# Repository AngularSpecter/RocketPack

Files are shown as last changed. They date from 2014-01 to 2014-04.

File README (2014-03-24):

*** Rocket Pack************************************

Project Synopsis
--------------------

Rocket pack is a development board based around the MSP430FR5739 microcontroller
and the Digi Xbee S3B Pro 900MHz zigbee radio.  The board is intended to 
facilitate broadcasting real time, high-rate sensor data over a range of several
hundred meters.  The board is designed to interface with custom built sensor 
packages, or with the TI sensorTag development board running custom firmware

Power Supply
----------------------
The board has on-board battery management designed specifically for single cell
lipo batteries, but will also take any voltage source between 3.3V and 5VDC.
The regualted 3.2V rail is availible on all three expansion headers as well as 
the CCdebugger header, which is designed specifically to power the sensorTag
development board.   

Communications
----------------------
The MSP430FR5739 contains two hardware USART's.  One USART is reserved for the
zigbee radio, while the other is broken out to both the serial data header and 
the ez430 programming/debug header.  All signals reqired for I2C, SPI or UART 
are availible on the serial data header

The firmware is written to buffer both inbound and outbound traffic.  The MCU 
pops bytes into the rx buffers in low power mode.  Once a line term char is RX'd,
LPM is exited and the full packet is processed.

No data is transmitted until a full packet is buffered.  Then it is transmitted
entirely before additional data is processed.  

Node power up sequence
-----------------------------------

sleep loop
-----------
1. Boot
2. Hold sensors in reset
3. Read and store radio address
4. Boot sensors
5. Read and store cal data
6. Sleep sensors

{
Auto discovery
---------------------
1. Poll magentometer
2. Broadcast host discover on trigger
3. Repeat until node select rxd
4. TX ACK
}

Wake up loop (on rx of node select)
-------------
7. TX ACK
8. Wait for command
   8a. Send cal data
   8b. Start data stream
  
On ~node select
----------------
1. Sleep sensors
2. Wait for wake up 

  Packet Formatting
  -----------------------------------------
  [0x01] [address] [0x00]
  host discover   0x01     Broadcast by the host to the base station to announce
                           its presence.
  [0x02] [command] [data] [0x00]                         
  command         0x02     Base -> node: command for remote node to execute
                           node -> base: return of command
                           
                  commands
                     0x01  Stop transmitting data
                     0x02  Start transmitting data
                     0x03  Change sensor profile
                     0x04  Reboot         

  cal data        0x03     Base -> node: Request calibration data 
                           node -> base: Return calibration data   
  
  data packet     0x04     node -> base: Data 

  node select     0x05     base -> node: address of node to be active..all other sleep

  ACK             0x06     command ACK
  
  NACK            0x07     command NACK
SensorTag
----------------------

 Errata
 ---------------------
 
 V0.1:
       Debug header location:  The location of the debug header interferes with 
       nearby pin headers, making it impossible to populate the debug header 
       with a right angle header and .1" pitch pin header.
       
       Specified load capacitors on the crystal are wrong.  The crystal will 
       stabilize on boot, but will not remain.
       
       Radio CONFIG pin is wired to MCU to allow easy entrance into command
       mode.  This should be connected to a different pin.

TO DO
------------------------

1.  MS430Firmware:  1.  Startup sleep mode -> poll mag and exit on high value
                    2.  Startup procedure -> broadcast calibration data
                    3.  Startup procedure -> read radio ID to store UID
                    4.  TX mirror         -> Prepend UID to TX'd packets
                    
2.  SensorTag       1.  Clean up firmware  -> remove deadwood
                    2.  
                    
3.  Labview         1.  Radio interface  ->  AT command mode control to select
                                             radio to listen to
                    2.  Sensor interface ->  Formalize calibration code
                    3.  Sensor interface ->  Formalize data processing
                    4.  Sensor interface ->  Add "remote globals"

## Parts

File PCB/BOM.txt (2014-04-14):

Index	Quantity	Part Number	Description	Customer Reference    Part ID

1   1 296-29235-1-ND     IC MCU 16BIT 16KB FRAM 38TSSOP       U3 
2   1 LTC1540CMS8#PBF-ND IC COMP NANOPOWER W/REF 8-MSOP       U2
3   1 296-17424-1-ND     IC REG LDO 3.2V 0.4A SOT23-5         U1

4 	2	311-1154-1-ND	CAP CER 22PF 50V 5% NPO 1206	            C7, C8
5	  1	311-1158-1-ND	CAP CER 47PF 50V 5% NPO 1206	            C6
6 	1 1276-1165-1-ND	CAP CER 0.1UF 50V 5% X7R 1206		        C4       
7 	1	1276-3085-1-ND	CAP CER 1UF  25V  5% X7R 1206		        C5
8 	1	311-1376-2-ND	CAP CER 10UF 16V Y5V 1206                 C3
9	  1	478-5784-1-ND	CAP CER 0.47UF 50V  5% X7R 1206	          C6
10	1	445-2344-1-ND	CAP CER 2200PF 630V 5% NP0 1206			      C1

11  1 311-47KERTR-ND      RES 47K OHM 1/4W 5% 1206 SMD        R1
12 	1	RMCF1206FT2M00CT-ND	RES 2M OHM 1/4W 1% 1206             R2
13	1	RHM1.18MCJCT-ND	    RES 1.18M OHM 1/4W 1% 1206 SMD      R3
14  1 311-100FRTR-ND      RES 100 OHM 1/4W 1% 1206 SMD        R4

15	1	XC1911CT-ND	CRYSTAL 32.768KHZ 12.5PF SMD                Q2
16  1 LTST-C150KGKT LED GREEN CLEAR 1206 SMD                  LED1

17	2	1212-1314-ND	SOCKET 4.2 MM SOLDER TAIL SINGLE
18  1 S9016E-06-ND	CONN HEADER .050" 6POS PCB R/A		
19	1	609-3754-ND	  CONN RECEPT 10POS DUAL VERT T/H

20	1	1175-1261-ND	CABLE CONNECT INTERNAL DVD .5M	

21	1	A9BBA-0603E-ND	FLEX CABLE - AFJ06A/AE06/AFJ06A

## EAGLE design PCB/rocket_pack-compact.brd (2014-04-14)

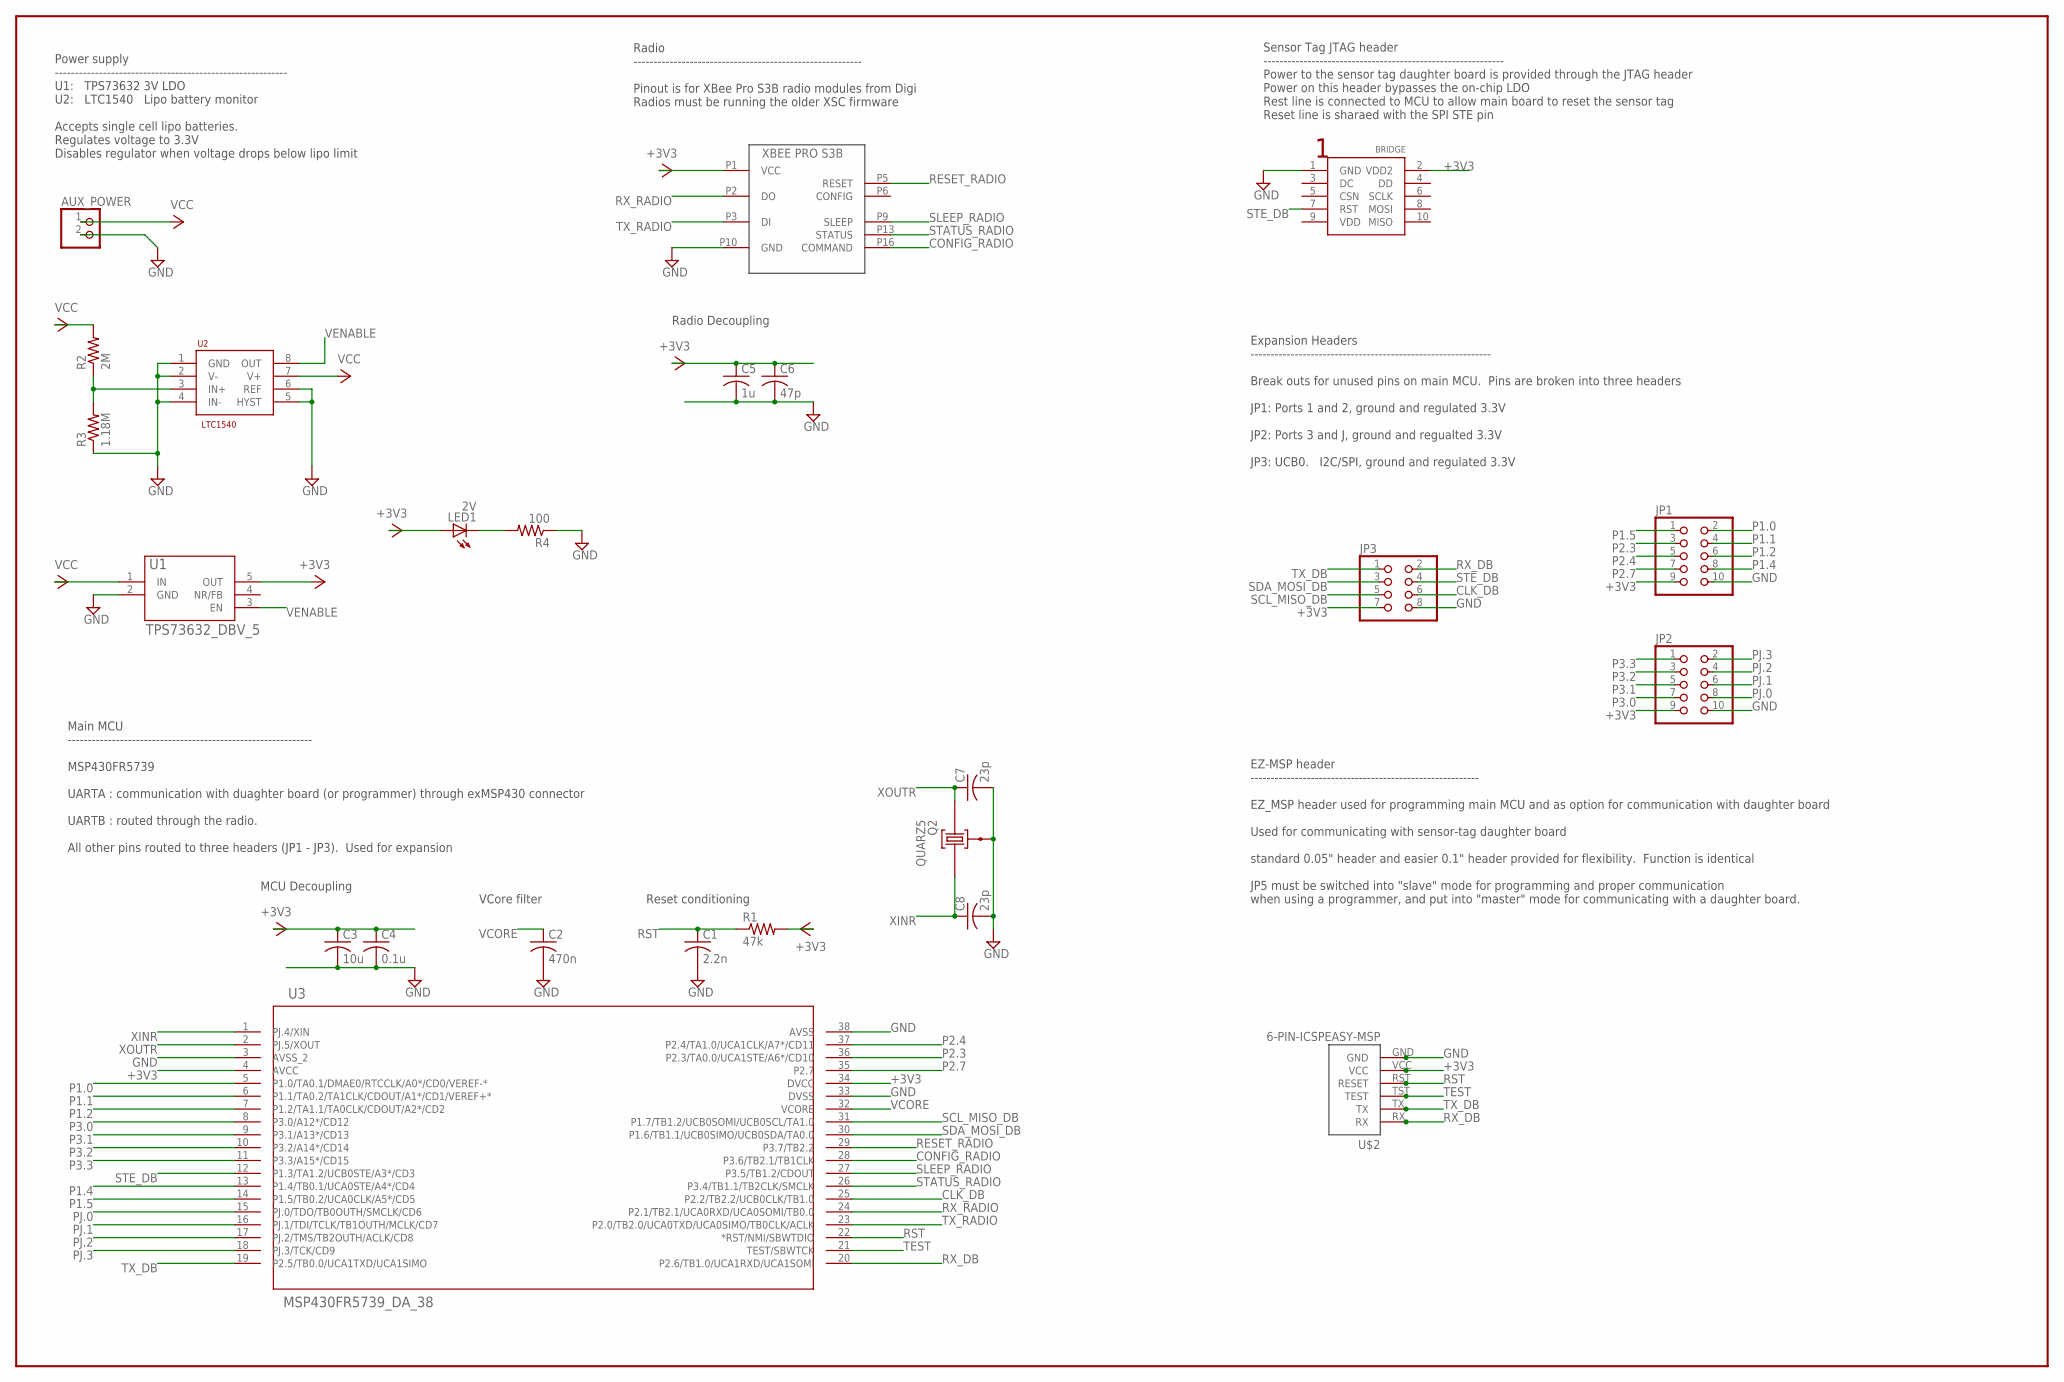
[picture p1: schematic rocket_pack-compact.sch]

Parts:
AUX_POWER: PINHD-1X2; 1X02
BRIDGE: CC-DEBUG; 2X5-1.27MM
C1: 2.2n; C1206
C2: 470n; C1206
C3: 10u; C1206
C4: 0.1u; C1206
C5: 1u; C1206
C6: 47p; C1206
C7, C8: 23p; C1206
JP1, JP2: PINHD-2X5; 2X05
JP3: PINHD-2X4; 2X04
LED1: 2V; 1206
Q2: QUARZ5
R1: 47k; R1206
R2: 2M; R1206
R3: 1.18M; R1206
R4: 100; R1206
U1: TPS73632_DBV_5; DBV5
U2: LTC1540; S8
U3: MSP430FR5739_DA_38; DA38
U$1: XBEE_PRO_S3B; PRO_S3B
U$2: 6-PIN-ICSPEASY-MSP; EASYMSP-6PIN

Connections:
+3V3: BRIDGE.2 (VDD2), C3.1, C4.1, C5.1, C6.1, JP1.9, JP2.9, JP3.7, LED1.A, R1.2, U1.5 (OUT), U3.4 (AVCC), U3.34 (DVCC), U$1.P1 (VCC), U$2.VCC
CLK_DB: JP3.6, U3.25 (P2.2/TB2.2/UCB0CLK/TB1.0)
CONFIG_RADIO: U3.28 (P3.6/TB2.1/TB1CLK), U$1.P16 (COMMAND)
GND: AUX_POWER.2, BRIDGE.1 (GND), C1.2, C2.2, C3.2, C4.2, C5.2, C6.2, C7.2, C8.2, JP1.10, JP2.10, JP3.8, Q2.GND@0 (0), R3.1, R4.1, U1.2 (GND), U2.1 (GND), U2.2 (V-), U2.4 (IN-), U2.5 (HYST), U2.6 (REF), U3.3 (AVSS_2), U3.33 (DVSS), U3.38 (AVSS), U$1.P10 (GND), U$2.GND
LED: LED1.C, R4.2
unnamed: R2.1, R3.2, U2.3 (IN+)
P1.0: JP1.2, U3.5 (P1.0/TA0.1/DMAE0/RTCCLK/A0*/CD0/VEREF-*)
P1.1: JP1.4, U3.6 (P1.1/TA0.2/TA1CLK/CDOUT/A1*/CD1/VEREF+*)
P1.2: JP1.6, U3.7 (P1.2/TA1.1/TA0CLK/CDOUT/A2*/CD2)
P1.4: JP1.8, U3.13 (P1.4/TB0.1/UCA0STE/A4*/CD4)
P1.5: JP1.1, U3.14 (P1.5/TB0.2/UCA0CLK/A5*/CD5)
P2.3: JP1.3, U3.36 (P2.3/TA0.0/UCA1STE/A6*/CD10)
P2.4: JP1.5, U3.37 (P2.4/TA1.0/UCA1CLK/A7*/CD11)
P2.7: JP1.7, U3.35 (P2.7)
P3.0: JP2.7, U3.8 (P3.0/A12*/CD12)
P3.1: JP2.5, U3.9 (P3.1/A13*/CD13)
P3.2: JP2.3, U3.10 (P3.2/A14*/CD14)
P3.3: JP2.1, U3.11 (P3.3/A15*/CD15)
PJ.0: JP2.8, U3.15 (PJ.0/TDO/TB0OUTH/SMCLK/CD6)
PJ.1: JP2.6, U3.16 (PJ.1/TDI/TCLK/TB1OUTH/MCLK/CD7)
PJ.2: JP2.4, U3.17 (PJ.2/TMS/TB2OUTH/ACLK/CD8)
PJ.3: JP2.2, U3.18 (PJ.3/TCK/CD9)
RESET_RADIO: U3.29 (P3.7/TB2.2), U$1.P5 (RESET)
RST: C1.1, R1.1, U3.22 (*RST/NMI/SBWTDIO), U$2.RST (RESET)
RX_DB: JP3.2, U3.20 (P2.6/TB1.0/UCA1RXD/UCA1SOMI), U$2.RX
RX_RADIO: U3.24 (P2.1/TB2.1/UCA0RXD/UCA0SOMI/TB0.0), U$1.P2 (DO)
SCL_MISO_DB: JP3.5, U3.31 (P1.7/TB1.2/UCB0SOMI/UCB0SCL/TA1.0)
SDA_MOSI_DB: JP3.3, U3.30 (P1.6/TB1.1/UCB0SIMO/UCB0SDA/TA0.0)
SLEEP_RADIO: U3.27 (P3.5/TB1.2/CDOUT), U$1.P9 (SLEEP)
STATUS_RADIO: U3.26 (P3.4/TB1.1/TB2CLK/SMCLK), U$1.P13 (STATUS)
STE_DB: BRIDGE.7 (RST), JP3.4, U3.12 (P1.3/TA1.2/UCB0STE/A3*/CD3)
TEST: U3.21 (TEST/SBWTCK), U$2.TST (TEST)
TX_DB: JP3.1, U3.19 (P2.5/TB0.0/UCA1TXD/UCA1SIMO), U$2.TX
TX_RADIO: U3.23 (P2.0/TB2.0/UCA0TXD/UCA0SIMO/TB0CLK/ACLK), U$1.P3 (DI)
VCC: AUX_POWER.1, R2.2, U1.1 (IN), U2.7 (V+)
VCORE: C2.1, U3.32 (VCORE)
VENABLE: U1.3 (EN), U2.8 (OUT)
XINR: C8.1, Q2.1, U3.1 (PJ.4/XIN)
XOUTR: C7.1, Q2.2, U3.2 (PJ.5/XOUT)

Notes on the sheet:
Radio Decoupling
MCU Decoupling
Power supply ---------------------------------------------------------- U1: TPS73632 3V LDO U2: LTC1540 Lipo battery monitor Accepts single cell lipo batteries. Regulates voltage to 3.3V Disables regulator when voltage drops below lipo limit
Radio --------------------------------------------------------- Pinout is for XBee Pro S3B radio modules from Digi Radios must be running the older XSC firmware
Sensor Tag JTAG header ------------------------------------------------------------ Power to the sensor tag daughter board is provided through the JTAG header Power on this header bypasses the on-chip LDO Rest line is connected to MCU to allow main board to reset the sensor tag Reset line is sharae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
Reset conditioning
VCore filter
Main MCU ------------------------------------------------------------- MSP430FR5739 UARTA : communication with duaghter board (or programmer) through exMSP430 connector UARTB : routed through the radio. All other pins routed to three headers (JP1 - JP3). Used for expansion
EZ-MSP header --------------------------------------------------------- EZ_MSP header used for programming main MCU and as option for communication with daughter board Used for communicating with sensor-tag daughter board standard 0.05" header and easier 0.1" header provided for flexibility. Functi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
Expansion Headers ------------------------------------------------------------ Break outs for unused pins on main MCU. Pins are broken into three headers JP1: Ports 1 and 2, ground and regulated 3.3V JP2: Ports 3 and J, ground and regualted 3.3V JP3: UCB0. I2C/SPI, ground and regulated 3.3V

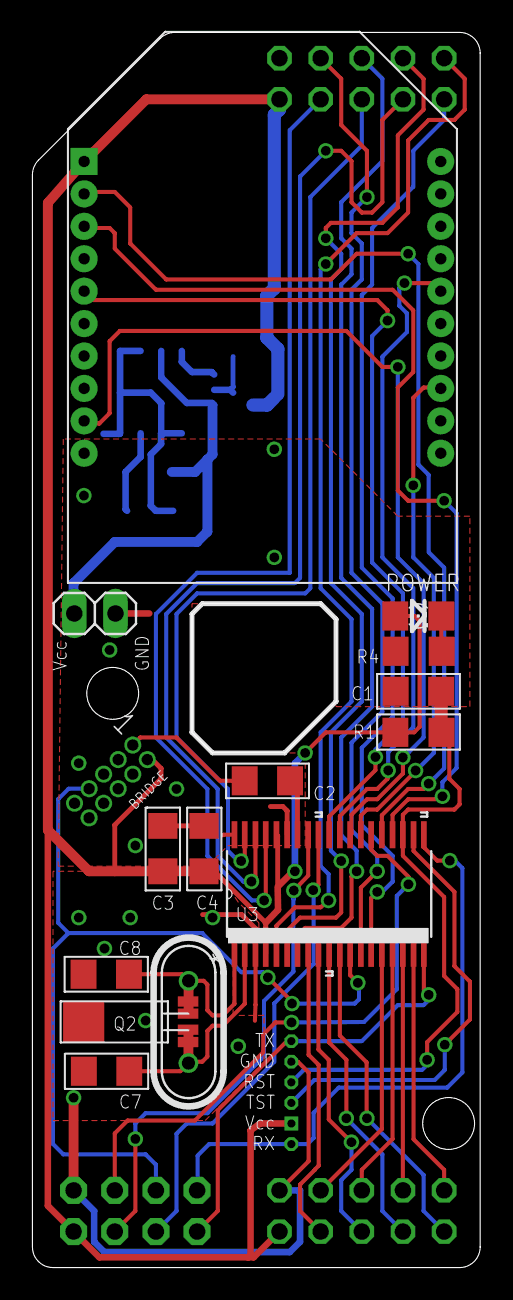
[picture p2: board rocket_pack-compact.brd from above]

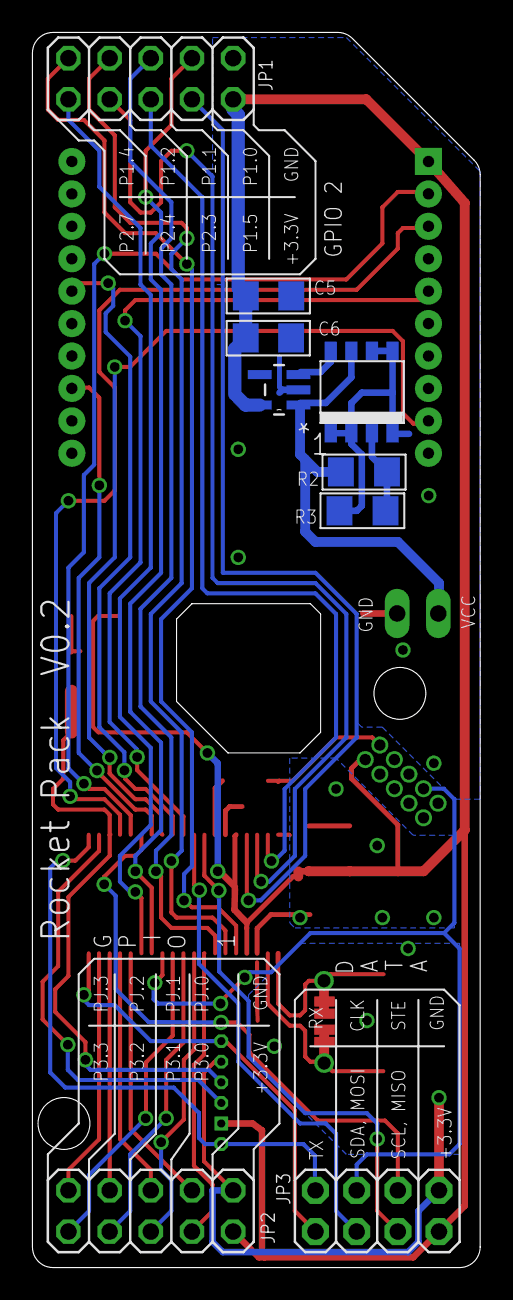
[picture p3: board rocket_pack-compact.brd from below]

Board: 2 copper layers, 27.6 x 76.2 mm, 24 parts (9 on the bottom side), 39 nets.

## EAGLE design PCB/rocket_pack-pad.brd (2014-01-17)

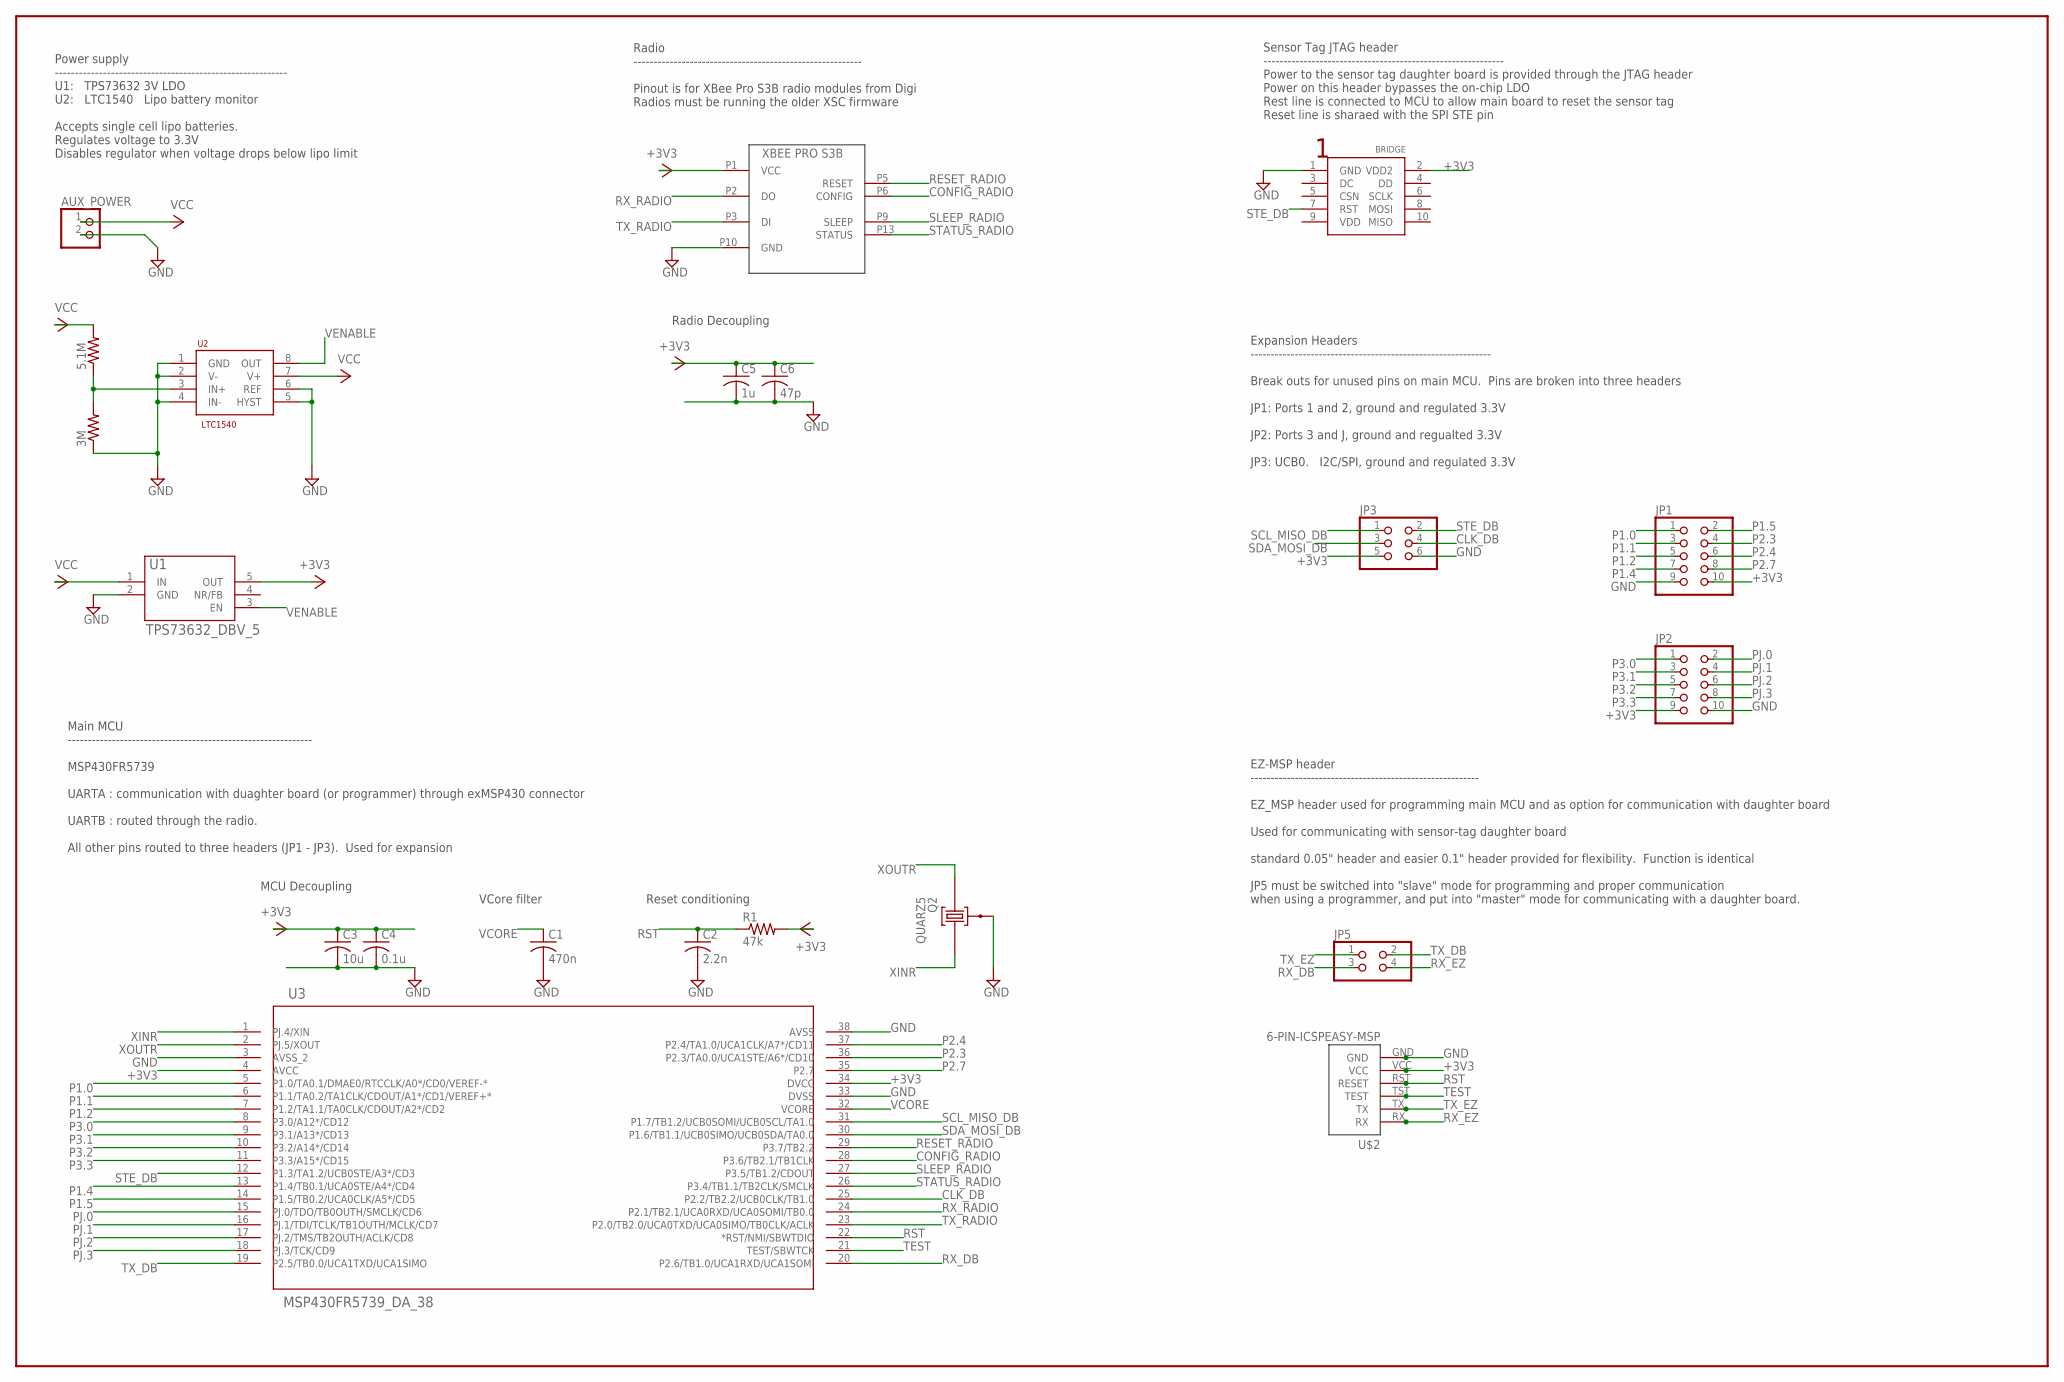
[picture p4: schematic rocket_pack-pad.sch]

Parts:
3M, 5.1M: R-US_R1206; R1206
AUX_POWER: PINHD-1X2; 1X02
BRIDGE: CC-DEBUG; 2X5-1.27MM
C1: 470n; C1206
C2: 2.2n; C1206
C3: 10u; C1206
C4: 0.1u; C1206
C5: 1u; C1206
C6: 47p; C1206
JP1, JP2: PINHD-2X5; 2X05
JP3: PINHD-2X3; 2X03
JP5: PINHD-2X2; 2X02
Q2: QUARZ5
R1: 47k; R1206
U1: TPS73632_DBV_5; DBV5
U2: LTC1540; S8
U3: MSP430FR5739_DA_38; DA38
U$1: XBEE_PRO_S3B; PRO_S3B
U$2: 6-PIN-ICSPEASY-MSP; EASYMSP-6PIN

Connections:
+3V3: BRIDGE.2 (VDD2), C3.1, C4.1, C5.1, C6.1, JP1.10, JP2.9, JP3.5, R1.2, U1.5 (OUT), U3.4 (AVCC), U3.34 (DVCC), U$1.P1 (VCC), U$2.VCC
CLK_DB: JP3.4, U3.25 (P2.2/TB2.2/UCB0CLK/TB1.0)
CONFIG_RADIO: U3.28 (P3.6/TB2.1/TB1CLK), U$1.P6 (CONFIG)
GND: 3M.1, AUX_POWER.2, BRIDGE.1 (GND), C1.2, C2.2, C3.2, C4.2, C5.2, C6.2, JP1.9, JP2.10, JP3.6, Q2.GND@0 (0), U1.2 (GND), U2.1 (GND), U2.2 (V-), U2.4 (IN-), U2.5 (HYST), U2.6 (REF), U3.3 (AVSS_2), U3.33 (DVSS), U3.38 (AVSS), U$1.P10 (GND), U$2.GND
unnamed: 3M.2, 5.1M.1, U2.3 (IN+)
P1.0: JP1.1, U3.5 (P1.0/TA0.1/DMAE0/RTCCLK/A0*/CD0/VEREF-*)
P1.1: JP1.3, U3.6 (P1.1/TA0.2/TA1CLK/CDOUT/A1*/CD1/VEREF+*)
P1.2: JP1.5, U3.7 (P1.2/TA1.1/TA0CLK/CDOUT/A2*/CD2)
P1.4: JP1.7, U3.13 (P1.4/TB0.1/UCA0STE/A4*/CD4)
P1.5: JP1.2, U3.14 (P1.5/TB0.2/UCA0CLK/A5*/CD5)
P2.3: JP1.4, U3.36 (P2.3/TA0.0/UCA1STE/A6*/CD10)
P2.4: JP1.6, U3.37 (P2.4/TA1.0/UCA1CLK/A7*/CD11)
P2.7: JP1.8, U3.35 (P2.7)
P3.0: JP2.1, U3.8 (P3.0/A12*/CD12)
P3.1: JP2.3, U3.9 (P3.1/A13*/CD13)
P3.2: JP2.5, U3.10 (P3.2/A14*/CD14)
P3.3: JP2.7, U3.11 (P3.3/A15*/CD15)
PJ.0: JP2.2, U3.15 (PJ.0/TDO/TB0OUTH/SMCLK/CD6)
PJ.1: JP2.4, U3.16 (PJ.1/TDI/TCLK/TB1OUTH/MCLK/CD7)
PJ.2: JP2.6, U3.17 (PJ.2/TMS/TB2OUTH/ACLK/CD8)
PJ.3: JP2.8, U3.18 (PJ.3/TCK/CD9)
RESET_RADIO: U3.29 (P3.7/TB2.2), U$1.P5 (RESET)
RST: C2.1, R1.1, U3.22 (*RST/NMI/SBWTDIO), U$2.RST (RESET)
RX_DB: JP5.3, U3.20 (P2.6/TB1.0/UCA1RXD/UCA1SOMI)
RX_EZ: JP5.4, U$2.RX
RX_RADIO: U3.24 (P2.1/TB2.1/UCA0RXD/UCA0SOMI/TB0.0), U$1.P2 (DO)
SCL_MISO_DB: JP3.1, U3.31 (P1.7/TB1.2/UCB0SOMI/UCB0SCL/TA1.0)
SDA_MOSI_DB: JP3.3, U3.30 (P1.6/TB1.1/UCB0SIMO/UCB0SDA/TA0.0)
SLEEP_RADIO: U3.27 (P3.5/TB1.2/CDOUT), U$1.P9 (SLEEP)
STATUS_RADIO: U3.26 (P3.4/TB1.1/TB2CLK/SMCLK), U$1.P13 (STATUS)
STE_DB: BRIDGE.7 (RST), JP3.2, U3.12 (P1.3/TA1.2/UCB0STE/A3*/CD3)
TEST: U3.21 (TEST/SBWTCK), U$2.TST (TEST)
TX_DB: JP5.2, U3.19 (P2.5/TB0.0/UCA1TXD/UCA1SIMO)
TX_EZ: JP5.1, U$2.TX
TX_RADIO: U3.23 (P2.0/TB2.0/UCA0TXD/UCA0SIMO/TB0CLK/ACLK), U$1.P3 (DI)
VCC: 5.1M.2, AUX_POWER.1, U1.1 (IN), U2.7 (V+)
VCORE: C1.1, U3.32 (VCORE)
VENABLE: U1.3 (EN), U2.8 (OUT)
XINR: Q2.1, U3.1 (PJ.4/XIN)
XOUTR: Q2.2, U3.2 (PJ.5/XOUT)

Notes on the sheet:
Radio Decoupling
MCU Decoupling
Power supply ---------------------------------------------------------- U1: TPS73632 3V LDO U2: LTC1540 Lipo battery monitor Accepts single cell lipo batteries. Regulates voltage to 3.3V Disables regulator when voltage drops below lipo limit
Radio --------------------------------------------------------- Pinout is for XBee Pro S3B radio modules from Digi Radios must be running the older XSC firmware
Sensor Tag JTAG header ------------------------------------------------------------ Power to the sensor tag daughter board is provided through the JTAG header Power on this header bypasses the on-chip LDO Rest line is connected to MCU to allow main board to reset the sensor tag Reset line is sharae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
Reset conditioning
VCore filter
Main MCU ------------------------------------------------------------- MSP430FR5739 UARTA : communication with duaghter board (or programmer) through exMSP430 connector UARTB : routed through the radio. All other pins routed to three headers (JP1 - JP3). Used for expansion
EZ-MSP header --------------------------------------------------------- EZ_MSP header used for programming main MCU and as option for communication with daughter board Used for communicating with sensor-tag daughter board standard 0.05" header and easier 0.1" header provided for flexibility. Functi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
Expansion Headers ------------------------------------------------------------ Break outs for unused pins on main MCU. Pins are broken into three headers JP1: Ports 1 and 2, ground and regulated 3.3V JP2: Ports 3 and J, ground and regualted 3.3V JP3: UCB0. I2C/SPI, ground and regulated 3.3V

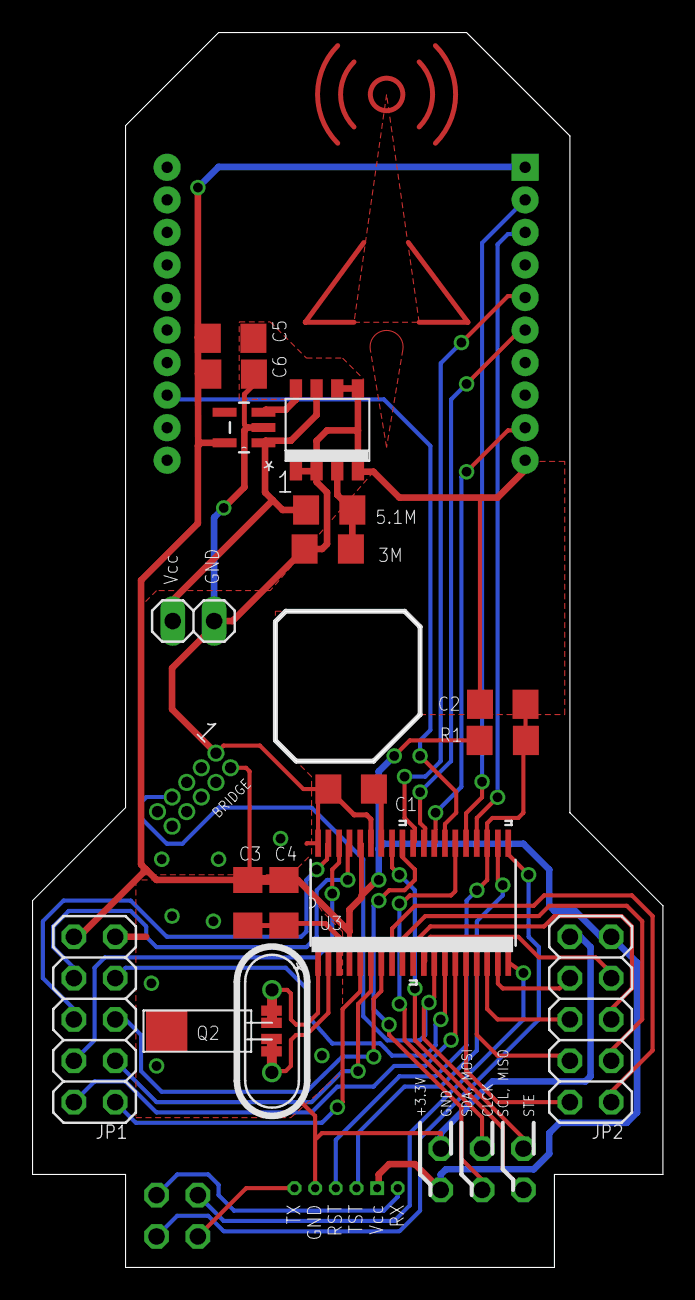
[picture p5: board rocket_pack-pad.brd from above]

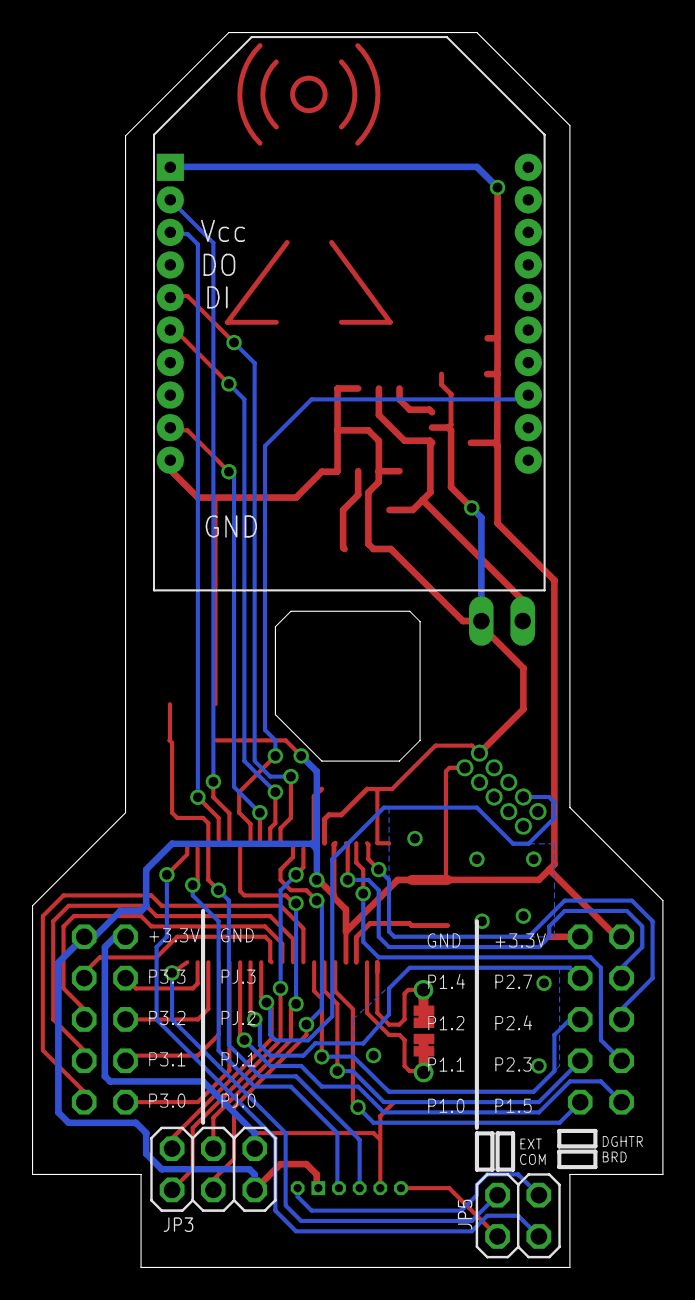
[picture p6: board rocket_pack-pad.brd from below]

Board: 2 copper layers, 38.7 x 75.9 mm, 21 parts (3 on the bottom side), 40 nets.

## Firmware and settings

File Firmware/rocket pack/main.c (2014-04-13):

#include <msp430FR5739.h>
#include "types.h"
#include "UART.h"
#include "buffer.h"
#include "radio.h"
#include "sensorTag.h"
#include "timing.h"

volatile unsigned char dbRXflag      = 0;
uint16                 radioAddress  = 0xff;
const unsigned int     magTrigger    = 0;
static const int       mag_poll_cnt  = 1;
unsigned char          heartbeat_TO  = 0;
volatile unsigned int  sensorMask    = 0;

void main(void) {

	uint16 poll_rate = 1100;



    WDTCTL = WDTPW | WDTHOLD;	// Stop watchdog timer

    mode proc_mode = SLEEPWAIT;

    //Initialize the SensorTag daughter board and hold in reset
    init_sensorTag();

   /*** Configure crystal ****************************/
    PJSEL0 |= BIT4 + BIT5;

    CSCTL0_H = 0xA5;						  //Enable Edit mode
    CSCTL1 = DCOFSEL0 + DCORSEL; // DCOFSEL1 ;  // Set max. DCO setting
    CSCTL2 = 0x0003 | 0x0030;                 // set ACLK = XT1; MCLK = DCO; SMCLK = DCO
    CSCTL3 = 0x0000;				          // set all dividers to 1;
    CSCTL4 = XT1DRIVE0 | XT1DRIVE1;			  // adjust crystal drive current

  /*  do
    {
      CSCTL5 &= ~XT1OFFG;                    // Clear XT1 fault flag
      SFRIFG1 &= ~OFIFG;
    }while (SFRIFG1&OFIFG);                  // Test oscillator fault flag
   */

    /*** Configure Radio UART ( UCA0 ) *****************/
    config_radio();					        //configure UART
    sleep_radio(TRUE);
    RADIOISR |=  RXIE;					    //enable rx interrupt


    /*** Configure Daughter Board UART ( UCA1 ) *****************/
    init_db_UART();    		    //configure UART
    DBISR |=  RXIE;             //enable rx interrupt

    _enable_interrupts();

    sleep_radio(FALSE);
    uint8 success = 0;

    /* Read the current address from the radio */

	//while (!success)    //loop until we can communicate with the radio
	//{
		//Read and cache the radio address
		success = radio_enter_CMD();
		if (success)
		{
		  success = radio_read_value(ADDRESS_DST, &radioAddress);
		  if (success) success = radio_leave_CMD();
		}

		//if(!success) delay(32768);
	//}

	 radio_set_term(0x00);
     start_heartbeat();

	 flush_buffer(&radio_rx_buffer);      //flush the command buffer

	 //broadcast that we
	 radio_send_byte(RADIOBOOT);
	 radio_send_byte(radioAddress);
	 radio_send_byte(0x00);

	 /** Operating modes  *********************************
	  *
	  *  SLEEPWAIT : The board starts in low power sleep wait.  Board is woken up with
	  *              a node select packet from the base station.  Board polls the magnetometer
	  *              and tx's a host discovery packet when triggered.
	  *
	  *  PRESTAGE  : Transition state to active mode.  The board waits for the base to request
	  *              calibration data and command the startup of the sensors
	  *
	  *  SHUTDOWN  : Transition state to sleep mode.  The board is shutdown.
	  *
	  *  ACTIVEMODE: The board listens to the sensor board and transmits everything over
	  *              radio
	  */



    // Main processing loop
    while(1) {

    	/************************************************************************/
    	//if there are incoming commands to process
    	if ( radio_rx_buffer.packets_rxd > 0)
    	{

    		unsigned int packet[4];
    		pop_command(&packet[0],&radio_rx_buffer);     //read the command off the stack

    		//Node select packets are handled the same regardless of operating mode
    		if ( packet[0] == NSEL )
    		{
				 if (packet[1] == radioAddress)  //if the packet is addressed to me
				 {
					 //ACK with my address
					 radio_send_byte(RADIOACK);
					 radio_send_byte(radioAddress);
					 radio_send_byte(0x00);
					 proc_mode    = PRESTAGE;
				 }else{
					 proc_mode    = SHUTDOWN;
				 }
    		}


    		//Host discovery packets are also handled the same regardless
    		if ( packet[0] == HOSTDISC )
    		{
    			//To make sure other radios don't overlap, we need to timeslot these replies
    			//This is done by waiting 128 times (4 ms ) the radio address
    			delay( 128 * radioAddress );
    			radio_send_byte(HOSTDISC);
    			radio_send_byte(radioAddress);
    			radio_send_byte(0x00);
    		}


    		//Only respond to cal requests in active mode
    		if (packet[0] == CAL && proc_mode == ACTIVEMODE )
    		{
    			//request cal data from the sensor board
    			db_send_byte(CALDATA);
    		}

    		//A data packet updates the sensor data mask (including autopoll mode)
    		if (packet[0] == DATA &&  proc_mode == ACTIVEMODE )
    		{

    			heartbeat_TO = packet[2];
    			heartbeat_cnt = 0;
    			//db_send_byte( sensorMask );

    			//if auto poll was previously active, but isn't now
    			if ( (sensorMask & 0x20) && !(packet[1] & 0x20) )
    			{
    				hs_interval_stop();
    			}


    			sensorMask = packet[1];  //turn off the autopoll flags (we will handle it ourselves)


    			//if the auto poll bit is set
				if ( sensorMask & 0x20 )
				{
					//since we handle polling here, don't pass the autopoll flag to the sensors
					hs_interval_start(poll_rate);

				}else if ( sensorMask & 0x80 )
				{
					//0x80 lets us pass on autopoll to the sensors... this is a 'max rate' operation
					hs_interval_stop();                   //just in case
				    db_send_byte( sensorMask | 0x20 );    //pass on the autopoll flag to the sensors
				}else
    			{
					//else we are just requesting a single frame
    				db_send_byte( sensorMask & 0x4F );
    			}




    		}

    		//An ACK packet in active mode is the heartbeat ping to keep the board alive
    		if ( packet[0] == RADIOACK && proc_mode == ACTIVEMODE)
    		{
    			heartbeat_cnt = 0;
    		}

    	}

    	/************************************************************************/
    	if ( db_tx_buffer.packets_rxd > 0)
		{
    		switch ( proc_mode )
			{
			case SLEEPWAIT :
				break;
			case ACTIVEMODE :
				break;
			}
		}


    	/************************************************************************/
    	if ( db_rx_buffer.packets_rxd > 0)
		{
    		switch ( proc_mode )
			{

    		//in sleepwait, incoming data is used to determine if we should announce wakeup
			case SLEEPWAIT :
				sensorTag_reset( TRUE );	//sleep the sensor board again

				//todo: process data and send host disc
				break;

			//in active mode, copy the full command to the TX buffer
			case ACTIVEMODE :
				command_copy( &db_rx_buffer, &radio_tx_buffer );
				break;
			}

		}

    	/************************************************************************/
    	if ( radio_tx_buffer.packets_rxd > 0)
		{
    		unsigned int length = command_length(&radio_tx_buffer);
    		unsigned int value;

    		while ( length-- )
			{
			buffer_pop( &value, &radio_tx_buffer );
			radio_send_byte( (char) value);
			}
		}


    	/*** Mode specific functions ********************************************/

    	switch ( proc_mode )
    	{
    	case ACTIVEMODE :
    		//Heartbeat code

    		if ( heartbeat_TO > 0 && heartbeat_cnt > heartbeat_TO )
    		{
    			proc_mode = SHUTDOWN;	//sleep the sensor
        		heartbeat_cnt = 0;
    		}
    		break;

    	// Wake up sensor board and prepare it for action
    	case PRESTAGE   :
    		sensorTag_reset(FALSE);
    		proc_mode = ACTIVEMODE;
    		break;

    	// Shutdown the sensor board
    	case SHUTDOWN   :
    		sensorTag_reset(TRUE);
    		proc_mode = SLEEPWAIT;
    		break;

    	case SLEEPWAIT  :
    		//Magnetometer poll
    		if ( heartbeat_cnt >= mag_poll_cnt )
    		{
    			//wake up the sensor board and request magnetometer data
    			sensorTag_reset( FALSE );
    			db_send_byte( MAGNET );
    			heartbeat_cnt = 0;
    		}
    		break;

    	}




    	/***********************************************************************/
    	//go to sleep (we will wake when something worth messing with happens)
    	if ( !(radio_tx_buffer.packets_rxd || db_tx_buffer.packets_rxd ||
    		   radio_rx_buffer.packets_rxd || db_rx_buffer.packets_rxd ) )
    	{
    		__bis_SR_register(LPM0_bits + GIE);
    	}


    }


}

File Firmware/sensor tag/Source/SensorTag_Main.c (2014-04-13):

/**************************************************************************************************
 *                                           Includes
 **************************************************************************************************/
#include <ioCC2541.h>
#include <hal_defs.h>
#include <hal_board_cfg.h>
#include "sleepTimer.h"
#include <hal_i2c.h>
#include <hal_sensor.h>
   
#include "uart.h"
#include "sensors.h"

/*************************************************************************************************
          Globals
**************************************************************************************************/
   volatile uint32 timeout = 0x000F;
  
  //Mode bit mask
  // 0 -> 3  :  Sensors
  //   4     :  Baro calibration data
  //   5     :  Auto poll (1 = auto poll, 0 = ping to poll)
  //   6     :  High speed mode (1 = decrease pressure sample rate)
  //   7     :  <reserved> Used in main board to trigger board centric autopoll
 

   //start up with all sensors sleeping
   uint8 active_sensors = 0; //BV(0) | BV(1) | BV(2) | BV(3) | BV(5);
   
volatile uint8 RXin = 1;
   
/*************************************************************************************************
          Main
**************************************************************************************************/
void main(void)
{
 
  HAL_BOARD_INIT();
  
  UART_init();
  U0CSR &= ~0x04;
  ENABLE_RX();
  
  /*setup sensors*/
  sensors_init();
  sensor_int_init();
  
  /* Setup LED's */  
  P1DIR |= BV(0);
  P0DIR |= BV(4);
  
  P1_0 = 0;
 
   
  start_gyro(); //start the gyro
  init_acc();   //start the accelerometer
  start_mag();
  start_baro();
  
  //zero_mag();
  
  EA = 1;

  SLEEPCMD |= 0x02;  //pm 2
  
  uint8 flag;
  uint8 IDbyte;
  
  
  uint8 baro_stage = 1;

  
   while(1){      
        
     if (RXin)
     {
      //If it is a cal data request 
      if ( active_sensors & BV(4) )
      {
        flag = 0x03;
        flush_data(&flag);
        baro_read_cal();
        
        //End of line char
        flag = 0x00;
        flush_byte(&flag);
        
      } else if ( active_sensors > 0 ) {
       
     //  P0_4 = 1;
    /**************************************************************************/
    /* Read and transmit sensor data                                          */
    flag = 0x04;
    flush_byte(&flag);   
    flush_byte(&active_sensors);
     
    /*---------------------------------------------------------------------*/ 
    //Read accelerometer and gyro
    
     if ( active_sensors & BV(0) )
     {       
       IDbyte = BV(0);
       flush_data(&IDbyte);
      
      while( !( acc_int_status() ) ); //wait for interrupt 
      read_acc();                 //read the accelerometer

      while( !(gyro_int_status() & BV(0) ) ); //wait for interrupt
      read_gyro();

     }
    
    /*---------------------------------------------------------------------*/
    //Read Magnetometer
    //start_interrupts(MAG_INT);
     
     if ( active_sensors & BV(1) )
     {
       
    
       IDbyte = BV(1);
       flush_data(&IDbyte);
       
       //PCON |= 1;
       while( !(mag_status() & 0x08 ) );
       read_mag();
 
      // mag_sleep(TRUE);  
     } 
    
    /*---------------------------------------------------------------------*/
    //Barometer
    
    //uint16 delay_ticks;
    uint8 baro_res = 2;
    
    
    if ( active_sensors & BV(2) )
    {
       IDbyte = BV(2);
       flush_data(&IDbyte);
       
       if (active_sensors & 0x40)
       {
         //delay_ticks = 0xFA00;
         baro_capture_press(baro_res);
         //while(delay_ticks--);
         baro_read_press(TRUE);
         
         //delay_ticks = 0xFA00;         
         baro_capture_temp();
         //while(delay_ticks--);
         baro_read_temp(TRUE); 
       }else{
      
         uint8 nullbyte = 3;
         switch (baro_stage)
         {
         case 1 :
            baro_capture_press(baro_res);
            baro_read_press(FALSE);
            baro_read_temp(FALSE);
            baro_stage++;
            break;
         case 2 :
            baro_read_press(TRUE);
            baro_read_temp(FALSE);
            baro_stage++;
            break;
         case 3 :
            baro_capture_temp();
            baro_read_press(FALSE);
            baro_read_temp(FALSE);
            baro_stage++;
            break;
         case 4 :
           baro_read_press(FALSE);
           baro_read_temp(TRUE);
           baro_stage = 1;
           break;
         }
       }

      //baro_shutdown();
    }
    
    /*---------------------------------------------------------------------*/
    //Humidity
    
    if ( active_sensors & BV(3) )
    {
      IDbyte = BV(3);
      flush_data(&IDbyte);
      humid_init();
      humid_read_humidity(TRUE);
    }
    
    /*---------------------------------------------------------------------*/

    
    //End of line char
    flag = 0x00;
    flush_byte(&flag);
    
    }
       

    if ( !(active_sensors & BV(5)) )        //if autopoll is off
    {
      P0_4 = 1;
      RXin = 0;                             //clear the RX flag
    }else{
      P0_4 = 0;
    }

    }
    
   IEN0 |= 0x04; 
   U0CSR &= ~0x04;
   }
   
}
/**************************************************************************************************
                                           CALL-BACKS
**************************************************************************************************/
_PRAGMA(vector=URX0_VECTOR)
__interrupt void RX0_ISR(void)
{
//  P1_0 = 1;
  IEN0 &= ~0x04;  
  U0CSR &= ~0x04;
  P1_0 ^= 1;
  active_sensors =  U0DBUF;
  RXin = 1;
//  P1_0 = 0;
}

/*Sleep Timer interrupt */

_PRAGMA(vector=ST_VECTOR)
__interrupt void SLEEP_ISR(void)
{
  SLEEP_TIMER_CLEAR();
}


/*
_PRAGMA(vector=P0INT_VECTOR) 
__interrupt void port0_ISR(void)
{
  if ( P0IFG &  BV(0) )         //If side switch
  {
   
  }
  //Clear the CPU interrupt flag for Port_0 PxIFG has to be cleared before PxIF
  P0IFG = 0;
  P0IF = 0;

}
*/

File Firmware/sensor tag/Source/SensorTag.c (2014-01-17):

/**************************************************************************************************
  Filename:       sensorTag.c
  Revised:        $Date: 2013-05-16 08:23:18 -0700 (Thu, 16 May 2013) $
  Revision:       $Revision: 34324 $

  Description:    This file contains the Sensor Tag sample application
                  for use with the TI Bluetooth Low Energy Protocol Stack.

  Copyright 2012-2013  Texas Instruments Incorporated. All rights reserved.

  IMPORTANT: Your use of this Software is limited to those specific rights
  granted under the terms of a software license agreement between the user
  who downloaded the software, his/her employer (which must be your employer)
  and Texas Instruments Incorporated (the "License").  You may not use this
  Software unless you agree to abide by the terms of the License. The License
  limits your use, and you acknowledge, that the Software may not be modified,
  copied or distributed unless embedded on a Texas Instruments microcontroller
  or used solely and exclusively in conjunction with a Texas Instruments radio
  frequency transceiver, which is integrated into your product.  Other than for
  the foregoing purpose, you may not use, reproduce, copy, prepare derivative
  works of, modify, distribute, perform, display or sell this Software and/or
  its documentation for any purpose.

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
  Should you have any questions regarding your right to use this Software,
  contact Texas Instruments Incorporated at www.TI.com.
**************************************************************************************************/

/*********************************************************************
 * INCLUDES
 */

#include "OnBoard.h"
#include "hal_adc.h"
#include "hal_led.h"
#include "hal_keys.h"
#include "hal_i2c.h"


//#include "hci.h"

// Sensor drivers
#include "sensorTag.h"
#include "hal_sensor.h"

#include "hal_irtemp.h"
#include "hal_acc.h"
#include "hal_humi.h"
#include "hal_mag.h"
#include "hal_bar.h"
#include "hal_gyro.h"

/*********************************************************************
 * MACROS
 */

/*********************************************************************
 * CONSTANTS
 */

// How often to perform sensor reads (milliseconds)
#define TEMP_DEFAULT_PERIOD                   1000
#define HUM_DEFAULT_PERIOD                    1000
#define BAR_DEFAULT_PERIOD                    1000
#define MAG_DEFAULT_PERIOD                    2000
#define ACC_DEFAULT_PERIOD                    1000
#define GYRO_DEFAULT_PERIOD                   1000

// Constants for two-stage reading
#define TEMP_MEAS_DELAY                       275   // Conversion time 250 ms
#define BAR_FSM_PERIOD                        80
#define ACC_FSM_PERIOD                        20
#define HUM_FSM_PERIOD                        20
#define GYRO_STARTUP_TIME                     60    // Start-up time max. 50 ms

// What is the advertising interval when device is discoverable (units of 625us, 160=100ms)
#define DEFAULT_ADVERTISING_INTERVAL          160

// General discoverable mode advertises indefinitely
#define DEFAULT_DISCOVERABLE_MODE             GAP_ADTYPE_FLAGS_LIMITED

// Minimum connection interval (units of 1.25ms, 80=100ms) if automatic parameter update request is enabled
#define DEFAULT_DESIRED_MIN_CONN_INTERVAL     80

// Maximum connection interval (units of 1.25ms, 800=1000ms) if automatic parameter update request is enabled
#define DEFAULT_DESIRED_MAX_CONN_INTERVAL     800

// Slave latency to use if automatic parameter update request is enabled
#define DEFAULT_DESIRED_SLAVE_LATENCY         0

// Supervision timeout value (units of 10ms, 1000=10s) if automatic parameter update request is enabled
#define DEFAULT_DESIRED_CONN_TIMEOUT          1000

// Whether to enable automatic parameter update request when a connection is formed
#define DEFAULT_ENABLE_UPDATE_REQUEST         TRUE

// Connection Pause Peripheral time value (in seconds)
#define DEFAULT_CONN_PAUSE_PERIPHERAL         8

// Company Identifier: Texas Instruments Inc. (13)
#define TI_COMPANY_ID                         0x000D

#define INVALID_CONNHANDLE                    0xFFFF

// Length of bd addr as a string
#define B_ADDR_STR_LEN                        15

#if defined ( PLUS_BROADCASTER )
  #define ADV_IN_CONN_WAIT                    500 // delay 500 ms
#endif

// Side key bit
#define SK_KEY_SIDE                           0x04

// Test mode bit
#define TEST_MODE_ENABLE                      0x80

// Common values for turning a sensor on and off + config/status
#define ST_CFG_SENSOR_DISABLE                 0x00
#define ST_CFG_SENSOR_ENABLE                  0x01
#define ST_CFG_CALIBRATE                      0x02
#define ST_CFG_ERROR                          0xFF

// System reset
#define ST_SYS_RESET_DELAY                    3000

/*********************************************************************
 * TYPEDEFS
 */

/*********************************************************************
 * GLOBAL VARIABLES
 */

/*********************************************************************
 * EXTERNAL VARIABLES
 */

/*********************************************************************
 * EXTERNAL FUNCTIONS
 */

/*********************************************************************
 * LOCAL VARIABLES
 */
static uint8 sensorTag_TaskID;   // Task ID for internal task/event processing



// Sensor State Variables
static bool   irTempEnabled = FALSE;
static bool   magEnabled = FALSE;
static bool   accEnabled = FALSE;
static bool   barEnabled = FALSE;
static bool   humiEnabled = FALSE;
static bool   gyroEnabled = FALSE;

static bool   barBusy = FALSE;
static uint8  humiState = 0;

static bool   sysResetRequest = FALSE;

static uint16 sensorMagPeriod = MAG_DEFAULT_PERIOD;
static uint16 sensorAccPeriod = ACC_DEFAULT_PERIOD;
static uint8  sensorGyroAxes = 0;
static bool   sensorGyroUpdateAxes = FALSE;
static uint16 selfTestResult = 0;
static bool   testMode = FALSE;

/*********************************************************************
 * LOCAL FUNCTIONS
 */
static void sensorTag_ProcessOSALMsg( osal_event_hdr_t *pMsg );
static void peripheralStateNotificationCB( gaprole_States_t newState );

static void readIrTempData( void );
static void readHumData( void );
static void readAccData( void );
static void readMagData( void );
static void readBarData( void );
static void readBarCalibration( void );
static void readGyroData( void );

static void barometerChangeCB( uint8 paramID );
static void irTempChangeCB( uint8 paramID );
static void accelChangeCB( uint8 paramID );
static void humidityChangeCB( uint8 paramID);
static void magnetometerChangeCB( uint8 paramID );
static void gyroChangeCB( uint8 paramID );
static void testChangeCB( uint8 paramID );

static void resetSensorSetup( void );
static void sensorTag_HandleKeys( uint8 shift, uint8 keys );
static void resetCharacteristicValue(uint16 servID, uint8 paramID, uint8 value, uint8 paramLen);
static void resetCharacteristicValues();
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

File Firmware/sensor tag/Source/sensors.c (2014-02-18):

#include "sensors.h"

void sensor_int_init(void)
{  
    //Gyro Interrupt  P0.1
   // P0SEL &= ~(BV(1));    /* Set pin function to GPIO */
   // P0DIR &= ~(BV(1));    /* Set pin direction to Input */
    //P0IEN |=   BV(1);     /* enable interrupt generation at port */
    
    //Accelerometer Interrupt  P0.2
    //P0SEL &= ~(BV(2));    /* Set pin function to GPIO */
    //P0DIR &= ~(BV(2));    /* Set pin direction to Input */
    //P0IEN |=   BV(2);     /* enable interrupt generation at port */
    
    //Magnetometer Interrupt  P0.6
   // P0SEL &= ~(BV(6));    /* Set pin function to GPIO */
   // P0DIR &= ~(BV(6));    /* Set pin direction to Input */
    //P0IEN |=   BV(6);     /* enable interrupt generation at port */

    //IR Temp Interrupt  P0.3
   // P0SEL &= ~(BV(3));    /* Set pin function to GPIO */
   // P0DIR &= ~(BV(3));    /* Set pin direction to Input */
    //P0IEN |=   BV(3);     /* enable interrupt generation at port */
    
    P0INP |= BV(1) | BV(2) | BV(6) | BV(3);
    //P2INP |= BV(5);    //enable pull down resistors on P0
    
    /* Clear any pending interrupts */
    //P0IFG = ~(BV(1));  //gyro 
   // P0IFG = ~(BV(2));  //accelerometer
    //P0IFG = ~(BV(6));  //magnetometer
    //P0IFG = ~(BV(3));  //IR Therm
    
    P0IFG = 0;
    P0IF  = 0;
    
    IEN1  |= BV(5);    /* enable CPU interrupt for all of port 0*/ 
}


void start_interrupts(uint8 mask)
{
   /* Clear any pending interrupts */
    P0IFG = ~(mask);   
    P0IEN |= mask;
    
    EA = 1;  //make sure interrupts are on
}

void stop_interrupts(uint8 mask)
{
    P0IEN &= ~mask;
}

void sensors_init(void)
{
  //Gyro is powered through P1.1
  P1DIR |= BV(1);
  GYRO_OFF();    //start off
  
  //Make sure the DCDC converter is on
  P0_7 = 1;
}

void burstRead(uint8 startADD, uint8 n_buffers)
{
  uint8 byte;
  uint8 checksum = 0x80;
  
  while(n_buffers--)
  {
    HalSensorReadReg(startADD++,&byte,1);
    checksum |= (byte == 0) << n_buffers;
    flush_data(&byte);
  }
  flush_byte(&checksum);
}
/*------------------------------------------------------------------------------
###############################################################################
Gyro
------------------------------------------------------------------------------*/
void start_gyro(void)
{
  GYRO_ON();
  
  HalI2CInit(GYRO_I2C_ADDRESS,   i2cClock_533KHZ);   //select the gyro
  
   //turn on all axes and lock clock to y
  //uint8 command = ~GYRO_PWR_MGM_STBY_ALL | GYRO_PWR_MGM_CLOCK_INT_OSC | GYRO_PWR_MGM_SLEEP;
  uint8 command = GYRO_PWR_MGM_CLOCK_INT_OSC;
  HalSensorWriteReg(GYRO_REG_PWR_MGM, &command,1);
  
  command = GYRO_INT_LATCH | GYRO_INT_CLEAR| GYRO_INT_DATA;
  HalSensorWriteReg(GYRO_REG_INT_CFG, &command, 1);
  
  
  //set sensor poll rate
  //Fsample = Finternal / (divider+1)
  command = 0 ;         //8 ms sample time
  HalSensorWriteReg(GYRO_REG_SMPLRT_DIV, &command, 1);
  
  //Finternal = 1kHz; Range = +-1000 s^-1; 188Hz LPF
  command = GYRO_DLPF_256 | GYRO_FS_2000;       
  HalSensorWriteReg(GYRO_REG_DLPF_FS, &command, 1);
}

void read_gyro()
{ 
  HalI2CInit(GYRO_I2C_ADDRESS,   i2cClock_533KHZ);   //select the gyro
  burstRead(GYRO_REG_GYRO_XOUT_H, 6);
}
  
void read_gyro_temp(uint16 *buffer)
{
  uint8 lsb, msb;
  
  HalI2CInit(GYRO_I2C_ADDRESS,   i2cClock_533KHZ);   //select the gyro
  
  HalSensorReadReg(GYRO_REG_TEMP_OUT_H,&msb,1);
  HalSensorReadReg(GYRO_REG_TEMP_OUT_L,&lsb,1);
 *buffer = (msb << 8 ) | (lsb);
}

uint8 gyro_int_status(void)
{
  uint8 status;
  HalI2CInit(GYRO_I2C_ADDRESS,   i2cClock_533KHZ);
  HalSensorReadReg(GYRO_REG_INT_STATUS ,&status,1);
  return status;
}

void gyro_sleep(bool sleep)
{
  uint8 power_mode;
  HalI2CInit(GYRO_I2C_ADDRESS,   i2cClock_533KHZ);
  HalSensorReadReg(GYRO_REG_PWR_MGM ,&power_mode,1);
  
  power_mode = (sleep)? power_mode | GYRO_PWR_MGM_SLEEP : power_mode & ~GYRO_PWR_MGM_SLEEP;
  HalSensorWriteReg(GYRO_REG_PWR_MGM , &power_mode, 1);
}

/****************************************************************************
 Accelerometer
*****************************************************************************/
void init_acc(void)
{
   //Select Accelerometer
  HalI2CInit(ACC_I2C_ADDRESS, i2cClock_267KHZ);
    
  uint8 command = 0x00;          //put to sleep
  HalSensorWriteReg(ACC_CTRL_REG1, &command, 1);
    
  //configure CTRL2 - 6.25Hz
  command = ACC_OWUFB | ACC_OWUFC;
  HalSensorWriteReg(ACC_CTRL_REG2, &command, 1);
  
  // Pulse the interrupt, active high and enable
  command = ACC_IEL | ACC_IEA | ACC_IEN;
  HalSensorWriteReg(ACC_INT_CTRL_REG1, &command, 1);
   
  //Enable interrupt for all axes
  command = ACC_ALLWU;
  HalSensorWriteReg(ACC_INT_CTRL_REG2, &command, 1);
  
  //Set the resolution to 8G and power on
  command = ACC_GSEL0 | ACC_GSEL1 | ACC_RES | ACC_PC1 | ACC_DRDYE; 
  HalSensorWriteReg(ACC_CTRL_REG1, &command, 1);
}


// Enable/disable interrupts
void acc_int_mode(bool interrupt)
{
  uint8 int_mode;
  HalI2CInit(ACC_I2C_ADDRESS, i2cClock_267KHZ);
  HalSensorReadReg(ACC_CTRL_REG1,&int_mode,1);
  
  int_mode = (interrupt)? int_mode | ACC_DRDYE : int_mode & ~ACC_DRDYE;
  HalSensorWriteReg(ACC_CTRL_REG1 , &int_mode, 1);
} 

// Sleep/wakeup sensor
void acc_sleep(bool sleep)
{
  uint8 power_mode;
  HalI2CInit(ACC_I2C_ADDRESS, i2cClock_267KHZ);
  HalSensorReadReg(ACC_CTRL_REG1 ,&power_mode,1);
  
  power_mode = (~sleep)? power_mode | ACC_PC1 : power_mode & ~ACC_PC1;
  HalSensorWriteReg(ACC_CTRL_REG1 , &power_mode, 1);
}

void read_acc(void)
{ 

  HalI2CInit(ACC_I2C_ADDRESS, i2cClock_267KHZ);
   burstRead(ACC_XOUT_L, 6);
}

uint8 acc_int_status(void)
{
  uint8 status;
  HalI2CInit(ACC_I2C_ADDRESS, i2cClock_267KHZ);
  HalSensorReadReg(ACC_INT_SOURCE1 ,&status,1);
  return (status & ACC_INT_DRDY);
}

/*------------------------------------------------------------------------------
###############################################################################
Magnetometer
------------------------------------------------------------------------------*/
void start_mag(void)
{
  //Select Magnetometer
  HalI2CInit(HAL_MAG3110_I2C_ADDRESS,i2cClock_267KHZ);
    
  uint8 command = MAG_AUTO_MRST;          //enable resets
  HalSensorWriteReg(MAG_CTRL_2, &command, 1);
  
  //command = MAG_CTRL1_TM | MAG_640_5HZ| MAG_CTRL1_AC;  //Triggered updates at 5Hz
  command = MAG_1280_40HZ | MAG_CTRL1_TM | MAG_CTRL1_AC;
  HalSensorWriteReg(MAG_CTRL_1, &command, 1);
}

void read_mag()
{ 
 // uint8 byte;

  HalI2CInit(HAL_MAG3110_I2C_ADDRESS,i2cClock_267KHZ);
  
 // byte = HAL_MAG3110_I2C_ADDRESS;
  //flush_data(&byte);
  
  burstRead(MAG_X_MSB, 6);
}

void mag_sleep(bool sleep)
{
  uint8 power_mode;
  
  HalI2CInit(HAL_MAG3110_I2C_ADDRESS,i2cClock_267KHZ);
  
  HalSensorReadReg(MAG_CTRL_1,&power_mode,1);  //read old state
  
  power_mode = (~sleep)? power_mode | MAG_CTRL1_AC : power_mode & ~MAG_CTRL1_AC;
  HalSensorWriteReg(MAG_CTRL_1, &power_mode, 1);
  
  
}
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

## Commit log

2014-01-17 Initial Commit
    Checking in V0.1 PCB's.
    [rocket_pack-compact.brd, rocket_pack-compact.sch, rocket_pack-pad.brd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]
2014-01-17 Sensor tag firmware
    Added sensor tag firmware
    Added supporting HAL files from TI BTLE stack
    Added IAR build environment
    [buildComponents.cfg, buildConfig.cfg, config.cfg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]
2014-01-25 Adding base code for MSP430
    [rocket_pack-compact.brd]
2014-01-25 Revert "Sensor tag firmware"
    This reverts commit df802b2d434db3963c2185d4e9ccf82e98226f94.
    [buildComponents.cfg, buildConfig.cfg, config.cfg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]
2014-01-27 attempted to add in lower power...no more room
    [buildComponents.cfg, buildConfig.cfg, config.cfg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]
2014-01-31 sleep timer and 'zero' header
    [rocket_pack-basic.brd, rocket_pack-basic.sch]
2014-02-04 Started rocket pack firmware
    Initial start to firmware for MSP430FR5739 board
    UART and clock initialization code
2014-02-05 firmware + PCB update
    Start of main firmware..mainly UART code
    Update to PCB to move "command" line from radio pin 6 to 16. Pin 6
    enters command mode on boot, pin 16 enables binary command mode
    (allowing the serial +++ handshake to be bypassed
    [rocket_pack-compact.brd, rocket_pack-compact.sch]
2014-02-16 sensor updates
    Fixed issue with magnetometer and gyro in tag firmware
    Updated labview code to match
    Decreased poll rate of barometer to half the main update rate. Can hit
    ~20Hz with everything but humidity (with temp/pressure at 10Hz) and 15Hz
    with everything (temp/press at 7 Hz).
    [SensorTag_Main.c, main.c, radio.h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]
2014-02-18 Fixing artifacts from merge
    [rocket_pack-compact.brd]
2014-03-24 Added sensor state machine
    Sensor state machine added with startup/shutdown handshaking sequence
    with base station as well as heartbeat.
    Issue with incoming (from base station) commands being blocked when
    radio is burst transmitting data.
    [rocket_pack-compact.brd]
2014-04-04 labview + MSP firmware
    Moved sensor polling to the MSP430 firmware (timer triggered) to
    generate uniform data rate
    addressed some bugs
    Working, single channel labview interface code
    [main.c, radio.c, radio.h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]
2014-04-14 Version 0.2
    Moved programming header to no longer interfere with headers
    Fixed pinout on radio module to allow binary programming
    Added power indicator LED
    [rocket_pack-compact.brd, rocket_pack-compact.sch]
